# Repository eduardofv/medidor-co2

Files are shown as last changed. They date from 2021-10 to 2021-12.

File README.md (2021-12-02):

# Un medidor de CO<sub>2</sub> que puedes hacer tu mismo

Cómo hacer un medidor de CO2 mínimo en requerimientos y costos, con partes que se pueden conseguir en México.

**Este medidor no es un instrumento de medición regulado por lo que su uso es con fines educativos, no se puede garantizar que se adecúe a un uso o necesidad específica**

El objetivo de este proyecto es describir cómo hice un medidor de CO<sub>2</sub> para uso casero. Mi esperanza es que sea lo suficientemente sencillo como para que niños de secundaria con una clase de electricidad o electrónica lo puedan hacer, con el apoyo de un buen maestro:

- Los costos se han mantenido al mínimo, calculo que en Noviembre de 2021 el costo total del proyecto debe ser de unos $700
- Las partes se pueden conseguir en México fácilmente, con excepción del sensor de CO2 que se puede conseguir en Aliexpress con envío a México
- Las herramientas y materiales son lo que comunmente se tiene en un pequeño taller de electrónica

## La importancia de la medición de CO2 desde COVID-19

La evidencia actual nos muestra que COVID-19 y muchas otras enfermedades se pueden contagiar al respirar el aire que otras personas respiraron previamente (y que puede contener al virus u otros patógenos). En un ambiente cerrado, como interiores de casas, salones de clases, comercios, etc. la principal fuente de dióxido de carbono (CO2), si no existen otras fuentes como estufas encendidas o motores de combustión, es la respiración de las personas. Por eso es que medir el CO2 nos puede dar una indicación de la probabilidad de respitar el aire que otra persona ya ha respirado. 

La concentración de CO2 se mide en partículas por millón (ppm).
 
- En exteriores, al aire libre, se suelen medir 400 ppm o menos. 
- En interiores con poca gente y buena ventilación se miden entre 400 y 700 ppm y es el nivel recomendado. Si la medición es mayor a esto se recomienda mejorar la ventilación.
- La Organización Mundial de la Salud (OMS) recomienda que la concentración de CO2 en interiores se mantenga por debajo de las 1,000 ppm.

Aunque no es perfecto y hay muchos factores que influyen en el riesgo real, medir el nivel de CO2 en los espacios cerrados nos puede dar una indicación de cuándo es necesario ventilar, o si es preferible evitar un espacio en forma precautoria.

*[TODO: Referencias a estudios, comunicados y estándares]*

## El proyecto "Haz tu mismo tu medidor de CO2"

Primero una **advetencia**: si lo que se requiere es una medición mas exacta y confiable con el fin de disminuir riesgos **se recomienda usar medidores de CO2 comerciales confiables y homologados**. Existen en el mercado muchos modelos confiables en una diversidad de precios. 

*[TODO: referencias a productos y documentacion sobre medidores]*

Dicho esto el presente proyecto tiene la intención de enseñar la importancia de la ventilación y de construir un medidor básico de CO2 que pueda servir como un proyecto de ciencias y tecnología sencillo y con cierta utilidad práctica. Sin embargo, inisito en que no es un medidor homologado y no se debe confiar únicamente en el para tomar decisiones de seguridad.

### Modelo actual básico

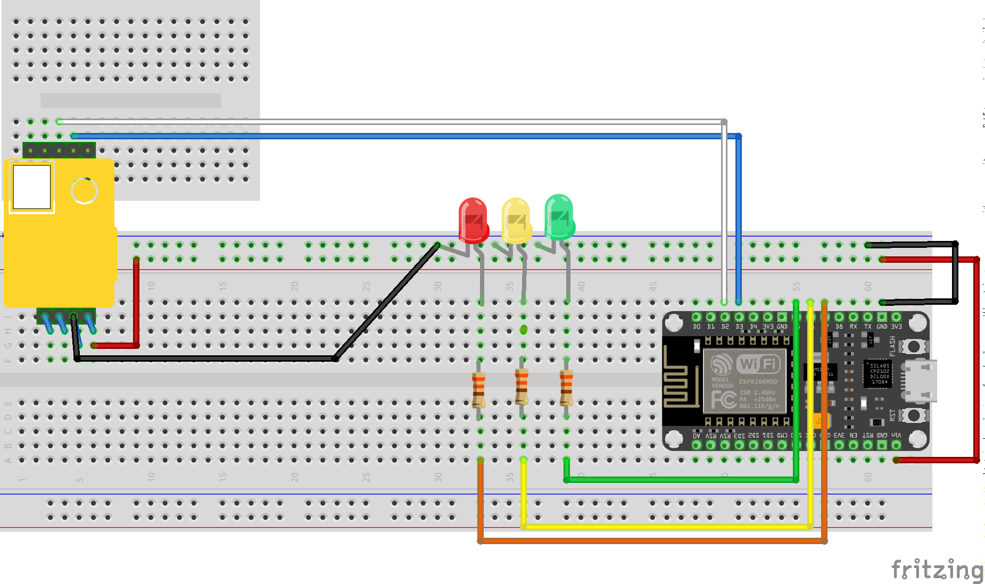
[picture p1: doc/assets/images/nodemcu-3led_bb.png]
diagrama protoboard


- *Microcontrolador*: NodeMCU v2
- *Sensor CO2*: Winsen MH-Z19
- 3 leds: verde, amarillo, rojo
- Plataforma de software: ESPHome

## Referencias

http://covidco2.exitcorp.net/documentacion/

https://www.hse.gov.uk/coronavirus/equipment-and-machinery/air-conditioning-and-ventilation/identifying-poorly-ventilated-areas.htm

https://ncceh.ca/sites/default/files/FINAL%20-%20Using%20Indoor%20CO2%20Sensors%20for%20COVID%20MAY%2017%202021.pdf

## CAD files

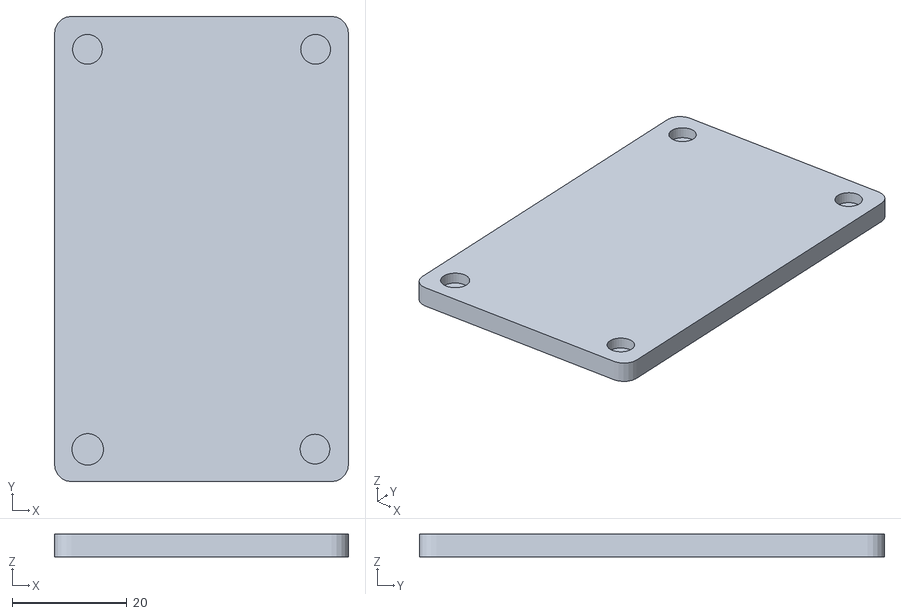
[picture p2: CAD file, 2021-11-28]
3D/tapa.stl
51.3 x 81.2 x 4.00

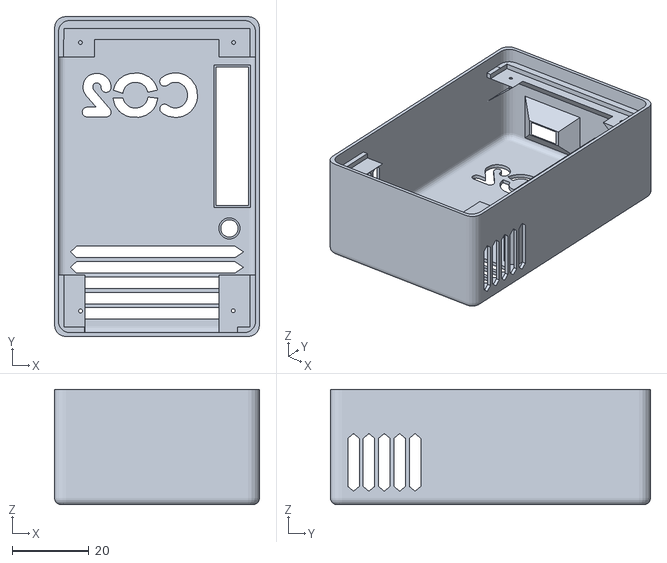
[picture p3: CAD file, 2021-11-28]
3D/caja.stl
53.3 x 83.2 x 30.0

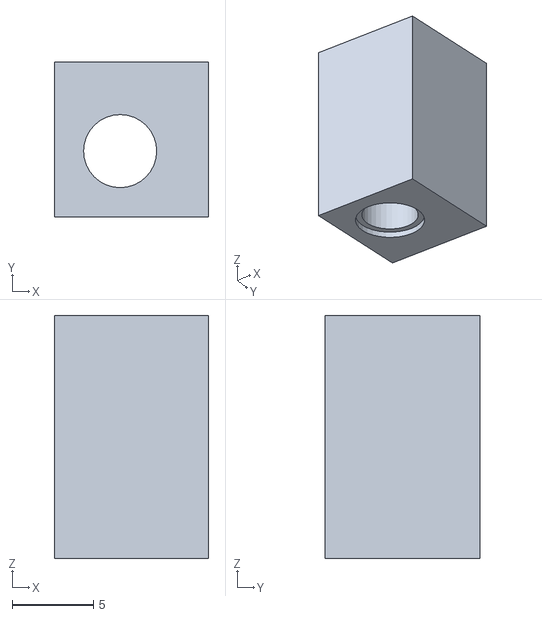
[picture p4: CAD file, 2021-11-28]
3D/caja boton 2.stl
9.50 x 9.56 x 15.0

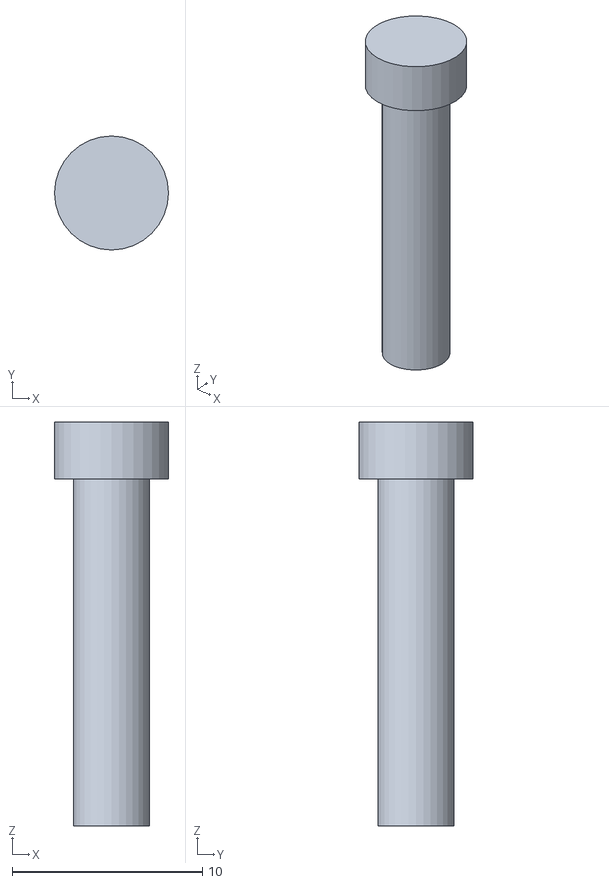
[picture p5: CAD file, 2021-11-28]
3D/boton.stl
6.00 x 6.00 x 21.3

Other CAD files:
3D/caja leds translucida.blend
3D/caja v1-prueba1.blend
3D/caja v1.blend

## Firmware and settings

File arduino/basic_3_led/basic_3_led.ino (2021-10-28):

/*
   Medidor CO2 MHZ19C con 3 LEDs (Arduino Nano)

*/

#include <MHZ19.h>
#include <SoftwareSerial.h>

//Configuración sensor MHZ19C
//  Pin RX Arduino conectado al pin TX del MHZ19
const int sensorRXpin = 7;
//  Pin TX Arduino conectado al pin RX del MHZ19
const int sensorTXpin = 6;
//  Objeto para sensor MHZ19
MHZ19 sensorCO2;
//  Puerto Serial de comunicacion con el MHZ19
SoftwareSerial puertoSerial(sensorRXpin, sensorTXpin);
//  Desactivar los mensajes de error al puerto serial del MHZ19
//  Dejarlo habilitado genera errores en cuando se conecta a algunos
//  cargadores USB
#define MHZ19_ERRORS 0

//Configuración de LEDs
//  LED nivel CO2 bueno (Verde)
const int ledBuenoPin = 2;
//  LED nivel CO2 regular (Amarillo)
const int ledRegularPin = 3;
//  LED nivel CO2 malo (Rojo)
const int ledMaloPin = 4;

//Configuración de niveles de CO2 para alertas
//  Nivel máximo para considerarlo bueno
const int maximoBueno = 700;
//    Nivel máximo para considerarlo regular
const int maximoRegular = 1000;
//    Cualquier valor por arriba, es malo

//Estas constantes nos ayudan a hacer mas claro el codigo
#define APAGADO 0
#define BUENO 1
#define REGULAR 2
#define MALO 3

//Definir el periodo de espera entre lecturas del sensor
//  si no, lo haria excesivamente rapido para el sensor (milisegundos)
const int periodoEspera = 2000;


//Encender los LEDs que correspondan al nivel
void mostrarNivel(int level) {
  //Apagar todos los pines
  digitalWrite(ledBuenoPin, LOW);
  digitalWrite(ledRegularPin, LOW);
  digitalWrite(ledMaloPin, LOW);

  switch (level) {
    case BUENO:
      digitalWrite(ledBuenoPin, HIGH);
      break;
    case REGULAR:
      digitalWrite(ledRegularPin, HIGH);
      break;
    case MALO:
      digitalWrite(ledMaloPin, HIGH);
      break;
  }
}


//Inicialización de componentes
void setup() {
  //Inicializar comunicacion a traves del USB con la computadora
  Serial.begin(9600);
  //Inicializar el puerto serial para conectar el sensor
  puertoSerial.begin(9600);

  //Asignar puerto serial al sensor
  sensorCO2.begin(puertoSerial);

  //Activar autocalibración (ver hoja de datos del sensor)
  sensorCO2.autoCalibration();

  //Inicializar pins para los LEDs
  pinMode(ledBuenoPin, OUTPUT);
  pinMode(ledRegularPin, OUTPUT);
  pinMode(ledMaloPin, OUTPUT);

  //Empezar con los LEDs apagados
  mostrarNivel(APAGADO);
}


//Ciclo iterativo
void loop() {

  //Leer el sensor de CO2
  int lecturaCO2 = sensorCO2.getCO2();
  //Mandar la lectura al USB
  Serial.println(lecturaCO2);

  //Determinar el nivel de CO2
  //  Si el nivel leido es cero es que hubo algún error, apagar los LEDs
  int nivelCO2 = APAGADO;
  if (lecturaCO2 <= maximoBueno) {
    nivelCO2 = BUENO;
  }
  else if (lecturaCO2 <= maximoRegular) {
    nivelCO2 = REGULAR;
  }
  else {
    nivelCO2 = MALO;
  }

  //Encender los LEDs que correspondan al nivel
  mostrarNivel(nivelCO2);

  //Esperar un tiempo antes de siguiente lectura
  delay(periodoEspera);
}

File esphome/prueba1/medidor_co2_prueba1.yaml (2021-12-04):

substitutions:
  nombre_dispositivo: medidor-co2-prueba1

  # niveles maximos por tipo de lectura
  # por arriba del nivel malo se considera muy malo
  nivel_bueno: "700.0"     # recomendado: 700
  nivel_regular: "1000.0"   # recomendado: 1000
  nivel_malo: "2000.0"     # recomendado: 2000

  # cada cuando se actualiza la medición del sensor de CO2
  tiempo_actualizacion: 5s

  # tiempo que se deja presionado el boton de calibrar para iniciar el proceso
  tiempo_boton_calibrar: 10s
  tiempo_boton_calibrar_max: 15s

  # tiempo que se deja presionado el boton de calibrar para iniciar el proceso
  tiempo_boton_usar_leds: 250ms
  tiempo_boton_usar_leds_max: 2s
  
  #Tiempo encendido/apagado del led de status 
  tiempo_strobe: 100ms

  # cuanto tiempo se debe dejar al aire libre para hacer la calibracion
  # la hoja de datos del MH-Z19C indica 20 minutos
  tiempo_calibracion: 20min #20min

  # Ejecutar el proceso de autocalibracion. Revisar su uso en la hoja de datos
  #   si el medidor va a estar en funcionamiento continuo (no se apaga nunca)
  #   en interiores de casas, oficinas, etc se puede habilitar
  autocalibracion: "false"

  
  # configuacion Wifi local y el portal cautivo (primera conexion)
  # si se usa archivo de secretos sustituir por esas variables
  ssid: "gdm" #!secret gdm_password
  ssid_password: !secret gdm_password
  ap_password: "" #!secret default_password
    


# Configuracion del MCU
esphome:
  name: $nombre_dispositivo
  platform: ESP8266
  board: nodemcuv2


# Habilitar logging pero restringir las de las luces
logger:
  logs:
    light: ERROR


# Haboilitar Home Assistant API
api:
  password: ""
  services:
    - service: mhz19_calibrate_zero
      then:
        - mhz19.calibrate_zero: mhz19_1
        - delay: 60s


ota:
  password: ""


wifi:
  ssid: $ssid
  password: $ssid_password

  # Enable fallback hotspot (captive portal) in case wifi connection fails
  # Habilitar el hotspot (portal cautivo) en caso de que la conexion wifi falle
  ap:
    ssid: $nombre_dispositivo
    password: $ap_password 


web_server:
  port: 80


captive_portal:


# Hardware del medidor de CO2

# bandera de estado de calibracion
globals:
  - id: calibrando
    type: bool
    restore_value: no
    initial_value: 'false'

#bandera para mostrar (encender) los leds o no
  - id: usar_leds
    type: bool
    restore_value: no
    initial_value: 'true'

# configuracion de luces
light:
  - platform: binary
    id: led_bueno
    internal: true
    output: led_verde
    effects:
      - strobe:

  - platform: binary
    id: led_regular
    internal: true
    output: led_amarillo
    effects:
      - strobe:

  - platform: binary
    id: led_malo
    internal: true
    output: led_rojo
    effects:
      - strobe:

  - platform: binary
    id: led_status
    internal: true
    output: led_azul
    effects:
      - strobe:
      - strobe:
          name: "strobe_rapido"
          colors:
            - state: true
              duration: $tiempo_strobe
            - state: false
              duration: $tiempo_strobe

  - platform: status_led
    name: "Status Led"
    pin: D2

# configuracion del hardware de conexiones de LEDs al MCU
output:
  - platform: gpio
    pin: D5
    id: led_verde

  - platform: gpio
    pin: D6
    id: led_amarillo

  - platform: gpio
    pin: D7
    id: led_rojo

  - platform: gpio
    pin: D8
    id: led_azul
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

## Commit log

2021-10-30 Agregar primer version de diagramas
    [nodemcu-3led-push.fzz]
2021-10-30 Actualizar diagramas. Pruebas de timeout en version con push button
2021-11-06 Nueva version del software de prueba para Node + 3 leds y diagramas
    [nodemcu-3led.fzz]
2021-11-28 Modelos 3D y actualizacion de prueba ESP
    [boton.stl, caja boton 2.stl, caja v1-prueba1.blend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]
2021-12-01 Otros modelos y actualizaciones
    [caja leds translucida.blend]
2021-12-01 Carga de fotos
2021-12-01 Carga de imagenes y actualizacion
2021-12-04 Un click para apagar los leds. Boton de status al GPIO 2 del nodemcu
